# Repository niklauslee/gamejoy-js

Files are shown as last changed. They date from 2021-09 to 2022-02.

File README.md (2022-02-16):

# GamejoyJS

## Overview

A retro-style game console programmable with JavaScript.

- [Raspberry Pi Pico](https://www.raspberrypi.org/products/raspberry-pi-pico/) (RP2040)
- [Kaluma](https://kalumajs.org) is used for JavaScript runtime.
- 1.44" 16-bit color TFT LCD (128x128)
- Magnetic buzzer
- TP4056 charger with 500mAh LiPo battery
- PCB designed by KiCAD
- 3D-printed case (PLA)

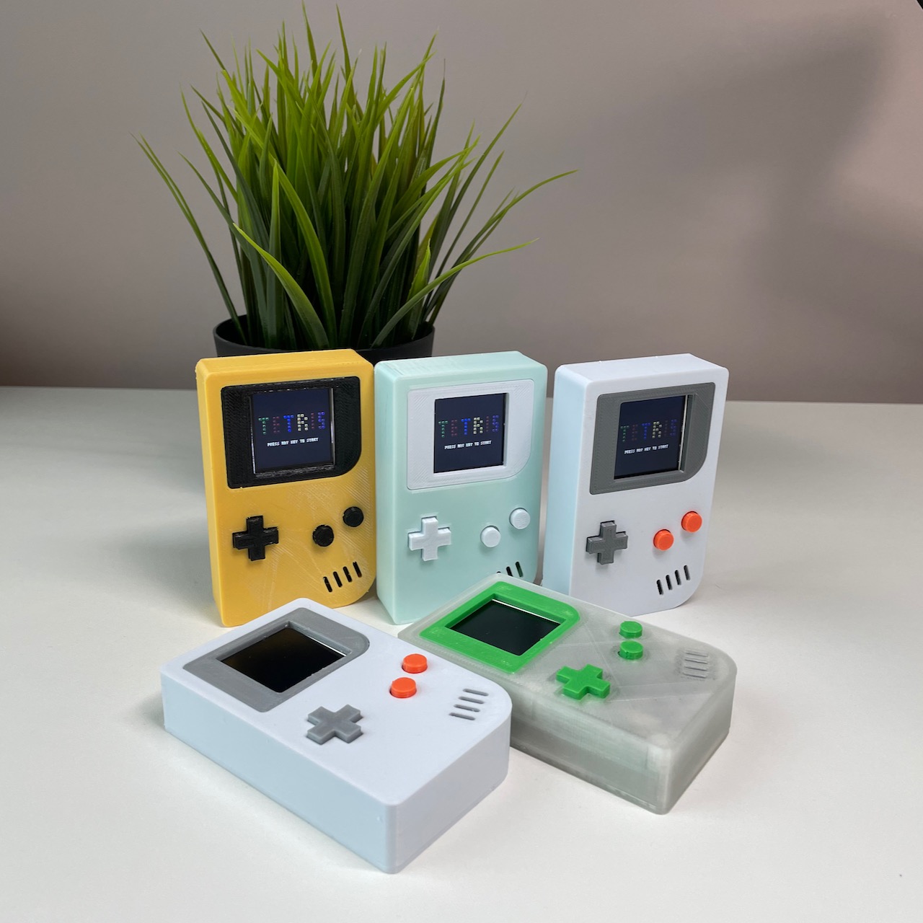
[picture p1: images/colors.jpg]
colors


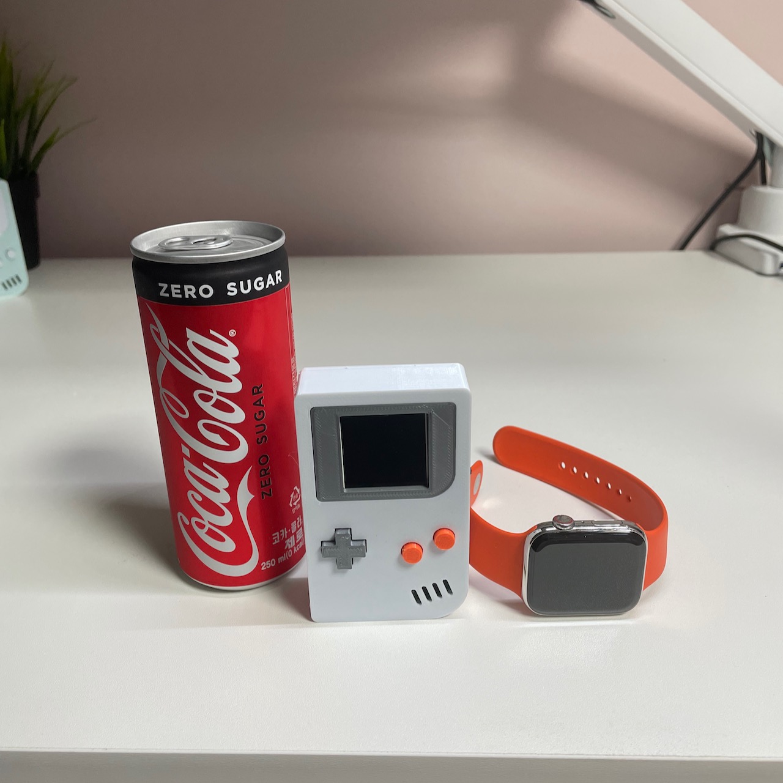
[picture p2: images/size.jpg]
size


__YouTube__

Video (https://youtu.be/LLxr6f_XCAQ?t=0s)

# Components

| Part | Quantity | Note |
| --- | --- | --- |
| Raspberry Pi Pico | 1 |  |
| Tactile Buttons | 6 | ITS-1105RT(5mm) - [(devicemart)](https://www.devicemart.co.kr/goods/view?no=36627) |
| Slide Switch | 1 | SK-12D02 - [(devicemart)](https://www.devicemart.co.kr/goods/view?no=14566) |
| Buzzer | 1 | Magnetic(IMT09B2703P) - [(devicemart)](https://www.devicemart.co.kr/goods/view?no=13992293) |
| LiPo Battery | 1 | 500mAh (35mmx30mmx5mm) - [(devicemart)](https://www.devicemart.co.kr/goods/view?no=1360753) |
| TP4056 Battery Charger | 1 | SZH-EK026 (micro-USB) - [(aliexpress)](https://www.aliexpress.com/item/1005002629114871.html) |
| Custom PCB | 1 | Designed with KiCAD, manufactured by [JLCPCB](https://jlcpcb.com/). KiCAD files in `kicad` folder |
| 1.44" TFT LCD (ST7735) | 1  | [(aliexpress)](https://www.aliexpress.com/item/32996979276.html) |
| Header Pins | | |
| 3D-printed case | | Designed with [Tinkercad](https://www.tinkercad.com/things/ey7LfFO1ldH). STL files in `design` folder |
| Tapping screws | 4 | M3x8 |

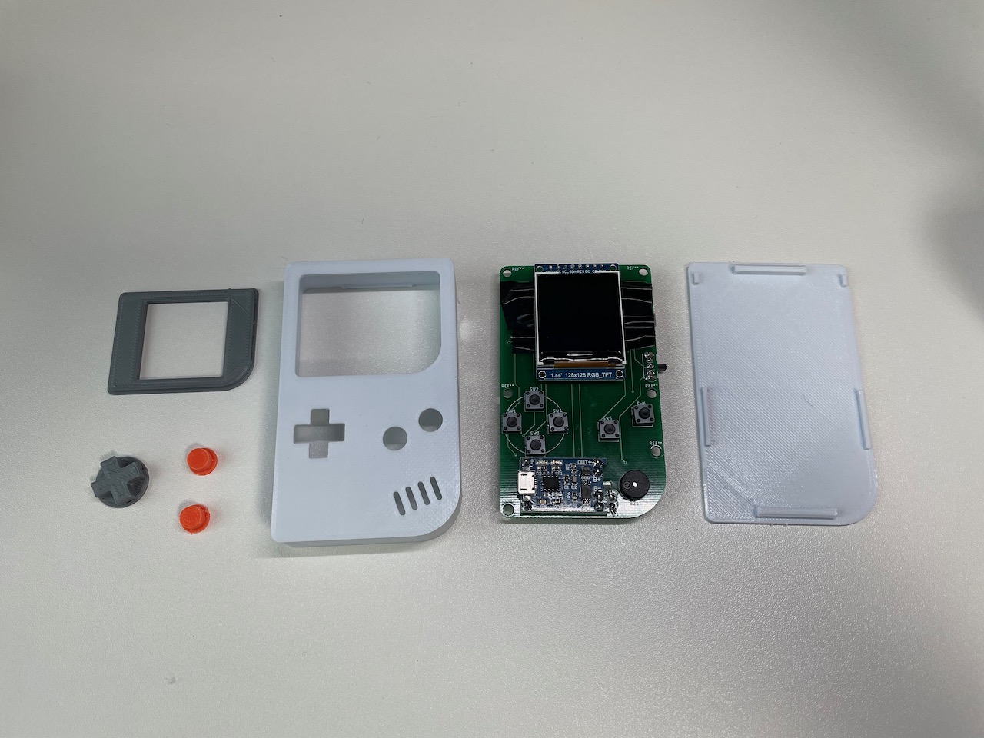
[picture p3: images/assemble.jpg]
assemble


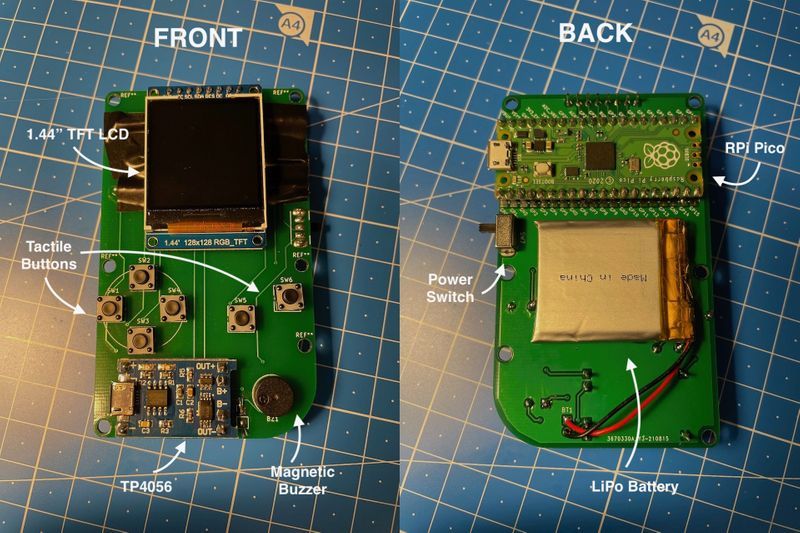
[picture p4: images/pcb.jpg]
pcb


## Preparations

Before uploading a game, please ensure that [Kaluma](https://kalumajs.org) firmware must be flashed in Raspberry Pi Pico.

[Kaluma CLI](https://github.com/kaluma-project/kaluma-cli) is also required to upload a game code.

## Upload Games

Currently only Tetris is available

- `./src/tetris.js`

Upload the Tetris game as below:

```sh
kaluma flash ./src/tetris --bundle --port <port>
```

## License

[MIT](LICENSE)

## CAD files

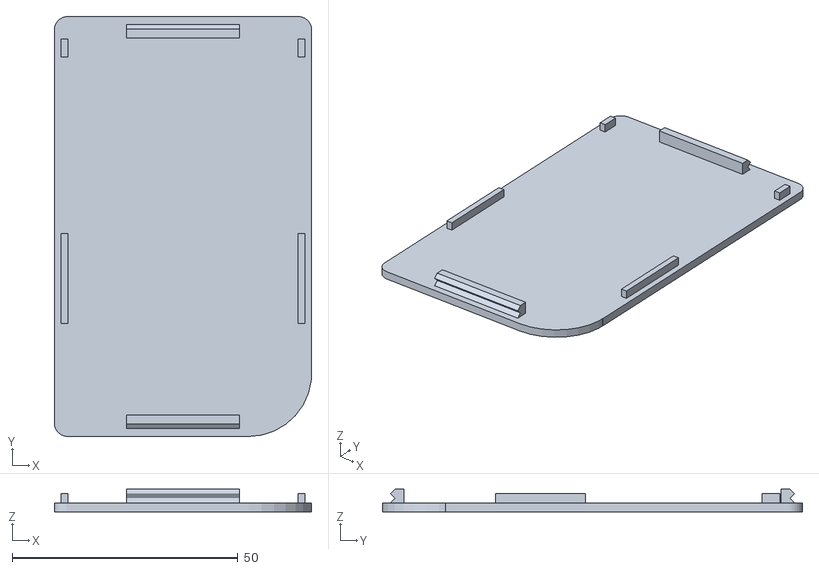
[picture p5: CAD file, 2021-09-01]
design/gj-back.stl
57.0 x 93.0 x 5.00

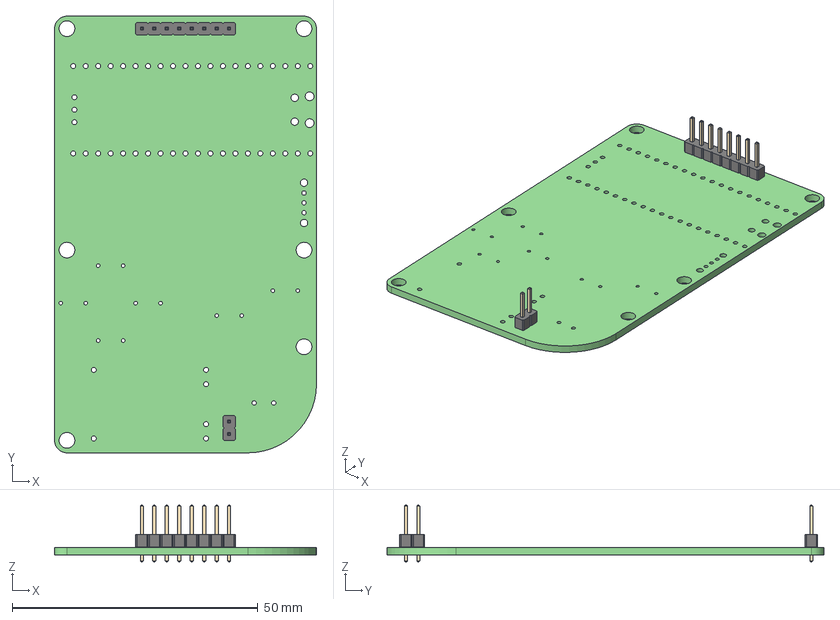
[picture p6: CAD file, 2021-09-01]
kicad/gamejoy/gamejoy.step
53.3 x 88.9 x 11.5 mm

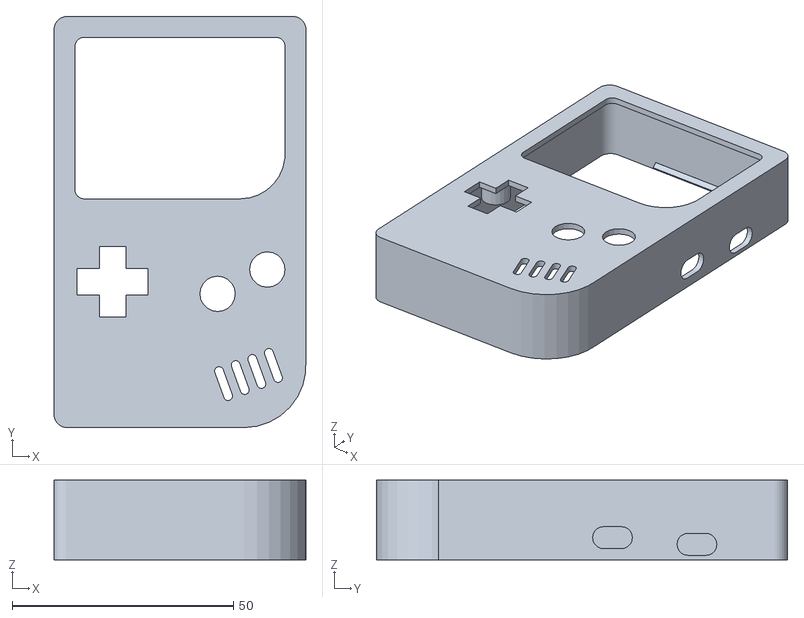
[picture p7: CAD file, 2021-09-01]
design/gj-body.stl
57.0 x 93.0 x 18.0

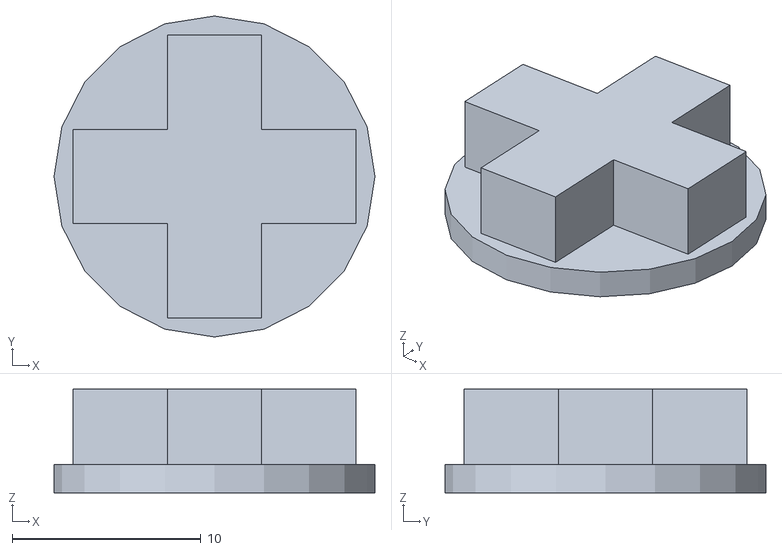
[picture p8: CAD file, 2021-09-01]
design/gj-joypad.stl
17.0 x 17.0 x 5.50

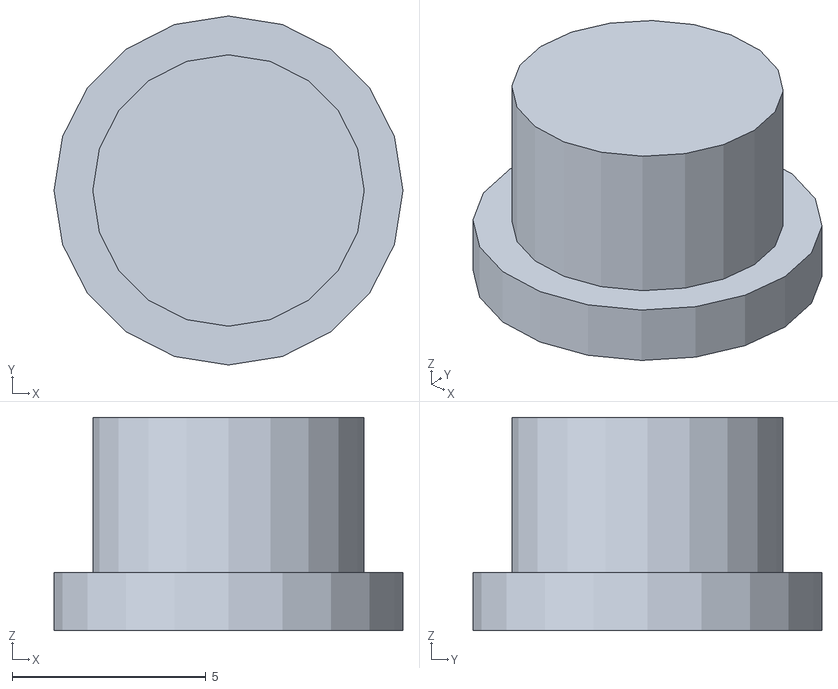
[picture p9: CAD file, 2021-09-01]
design/gj-button.stl
9.00 x 9.00 x 5.50

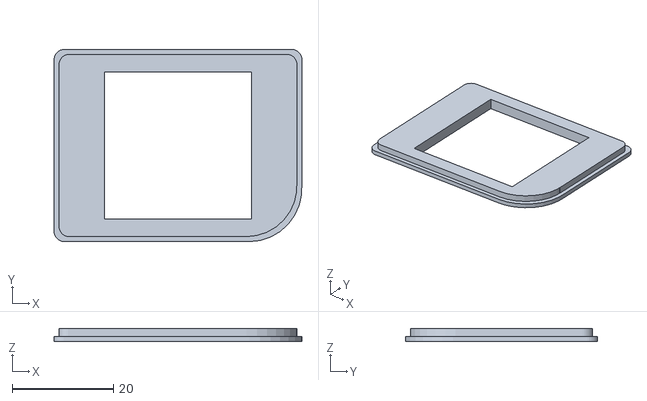
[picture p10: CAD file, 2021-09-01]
design/gj-bezel.stl
49.0 x 38.0 x 2.50

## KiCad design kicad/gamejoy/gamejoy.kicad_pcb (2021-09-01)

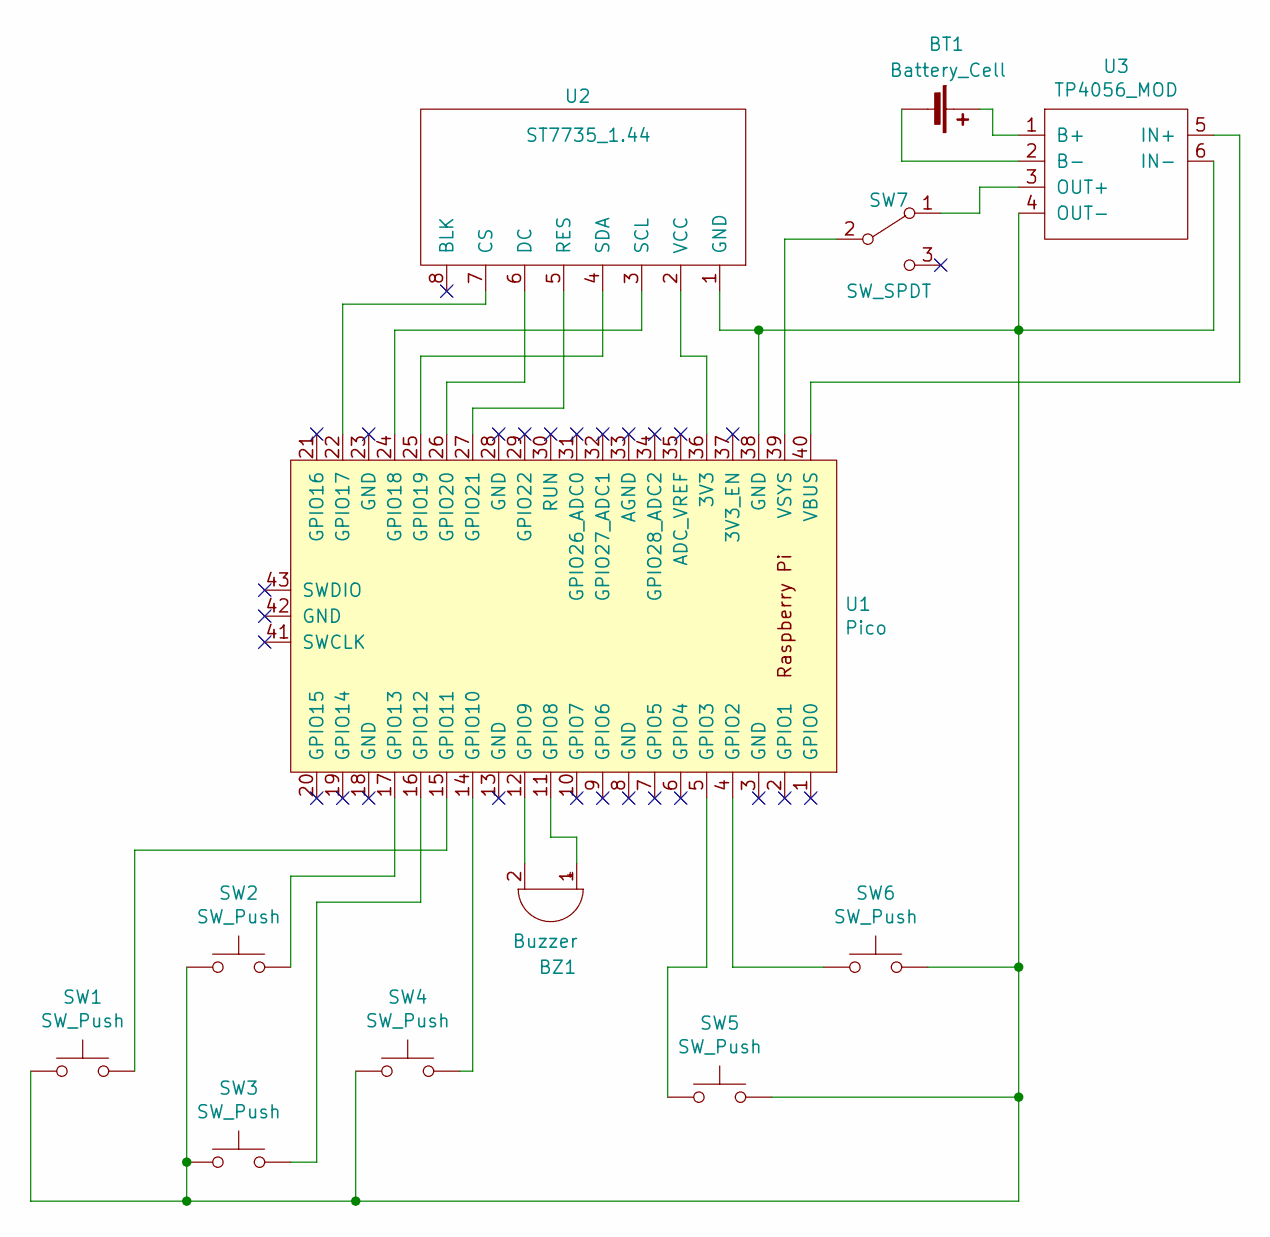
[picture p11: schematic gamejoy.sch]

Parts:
BT1: Battery_Cell; PinHeader_1x02_P2.54mm_Vertical
BZ1: Buzzer; MagneticBuzzer_PUI_AT-0927-TT-6-R
SW1, SW2, SW3, SW4, SW5, SW6: SW_Push; Button_Tactile_6.2mm_Square
SW7: SW_SPDT; SW_CuK_OS102011MA1QN1_SPDT_Angled
U1: Pico; RPi_Pico_SMD_TH
U2: ST7735_1.44; PinHeader_1x08_P2.54mm_Vertical
U3: TP4056_MOD

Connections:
unnamed: BT1.1 (+), U3.1 (B+)
unnamed: BT1.2 (-), U3.2 (B-)
unnamed: BZ1.1 (-), U1.11 (GPIO8)
unnamed: BZ1.2 (+), U1.12 (GPIO9)
unnamed: SW1.1, SW2.1, SW3.1, SW4.1, SW5.2, SW6.2, U1.38 (GND), U2.1 (GND), U3.4 (OUT-), U3.6 (IN-)
unnamed: SW1.2, U1.15 (GPIO11)
unnamed: SW2.2, U1.17 (GPIO13)
unnamed: SW3.2, U1.16 (GPIO12)
unnamed: SW4.2, U1.14 (GPIO10)
unnamed: SW5.1, U1.5 (GPIO3)
unnamed: SW6.1, U1.4 (GPIO2)
unnamed: SW7.1 (A), U3.3 (OUT+)
unnamed: SW7.2 (B), U1.39 (VSYS)
unnamed: U1.22 (GPIO17), U2.7 (CS)
unnamed: U1.24 (GPIO18), U2.3 (SCL)
unnamed: U1.25 (GPIO19), U2.4 (SDA)
unnamed: U1.26 (GPIO20), U2.6 (DC)
unnamed: U1.27 (GPIO21), U2.5 (RES)
unnamed: U1.36 (3V3), U2.2 (VCC)
unnamed: U1.40 (VBUS), U3.5 (IN+)

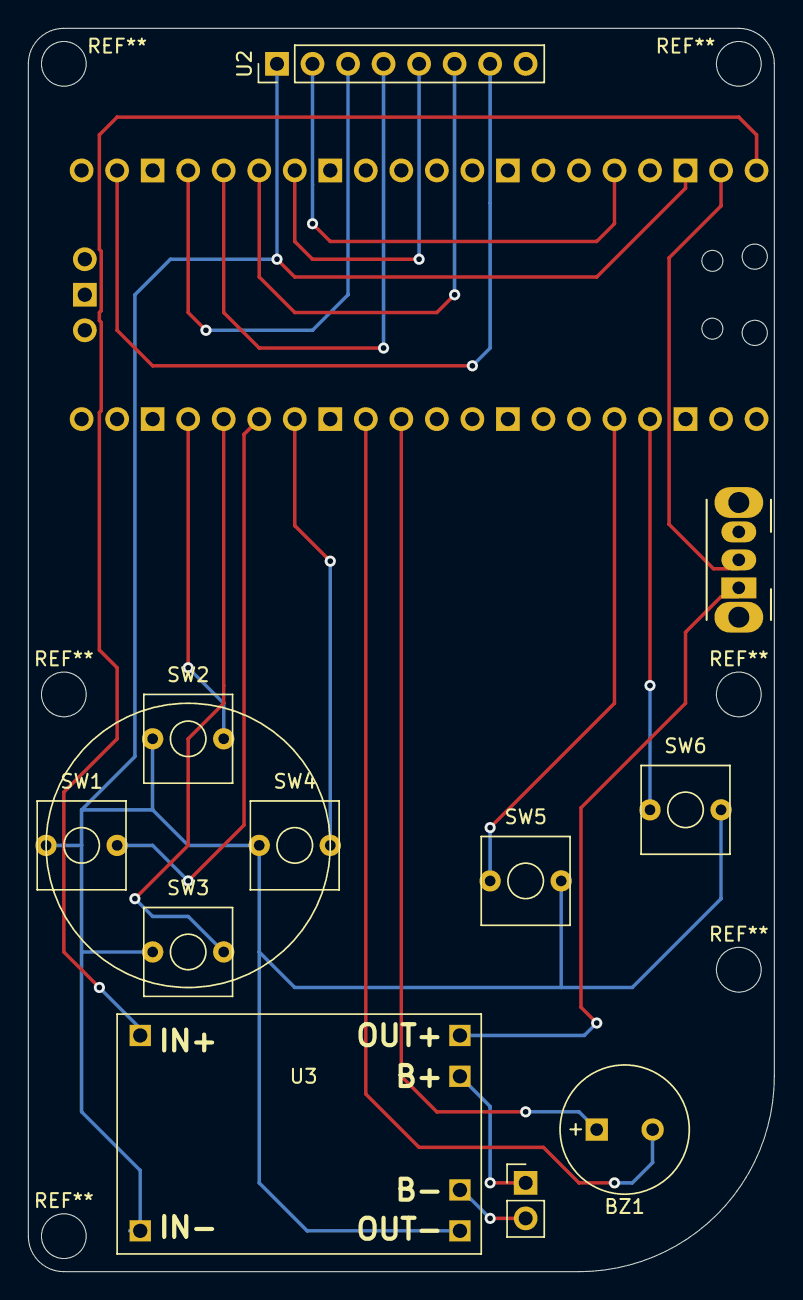
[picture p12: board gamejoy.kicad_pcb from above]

Board: 2 copper layers, 53.3 x 88.9 mm, 12 parts (1 on the bottom side), 20 nets.
